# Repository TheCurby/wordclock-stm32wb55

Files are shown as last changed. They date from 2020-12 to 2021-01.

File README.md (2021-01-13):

# Introduction
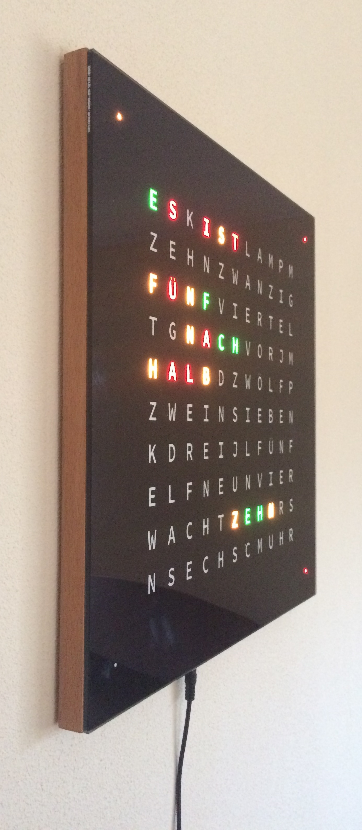
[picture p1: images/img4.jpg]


**ℹ️`This wordclock project contains a simulator. This simulator is using the same sources as the STM32 project. So you can explore this project without building it.`**

**⚠️`This project contains some small smd parts. You should be able to solder VQFN parts.`**

This wordclock is based on a STM32WB55CEU6 microcontroller placed on a custom printed circuit board.
It is designed using the STM32CubeIDE without LL or HAL Driver, just CMSIS.
It is strongly encapsulated in classes and written in C++.
This project only provides a pcb and the firmware/software. An eclosure has to be designed by yourself.
You have to solder the LEDs directly on the pcb and no stripes are needed. You can use SK6812 or WS2812B.
You can use DS18B20 or DS18S20.

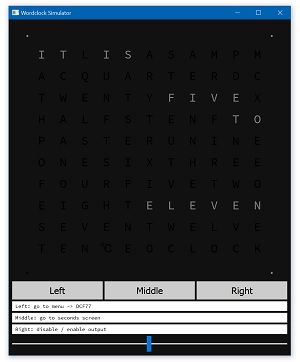
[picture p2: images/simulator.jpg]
On the PCB are three capacitive touch sensors. The microcontroller provides the possibility to use internal touch sensors but I decided to use MTCH105 instead. The sensors are placed directly in copper. As an alternative there is a socket to plug in mechanical switches.

The STM32WB55CEU6 provides the possibility of BLE connectivity on chip. The antenna is implemented on the PCB. There is no app programmed yet and no support implemented in the firmware yet. Feel free to contribute this. 
The wordclock is designed to work without external tools like apps or remote control. The goal is that every functionality can be configured using the cap keys of the clock and an app should only be optional and should not deliver additional possibilities.

Of course you can use any DCF77 module you want. But the PCB and firmware is designed to use the following module: https://de.elv.com/dcf-empfangsmodul-dcf-2-091610

The clock can be powered using a 5V to 18V supply. 

<table border="0" style="border:0px;">
<tr><td>
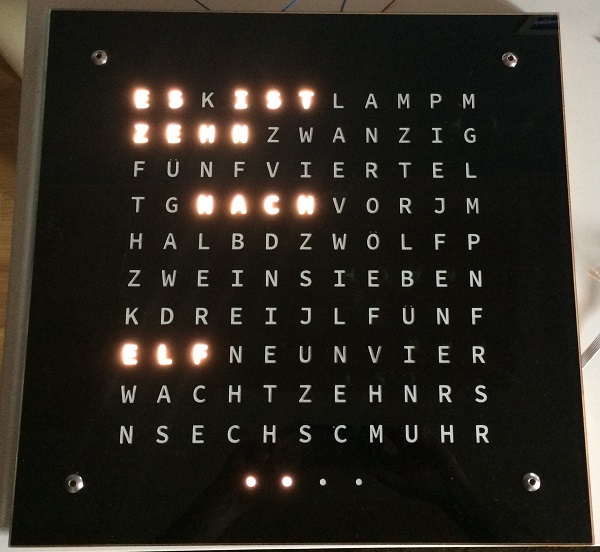
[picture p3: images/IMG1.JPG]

</td><td>
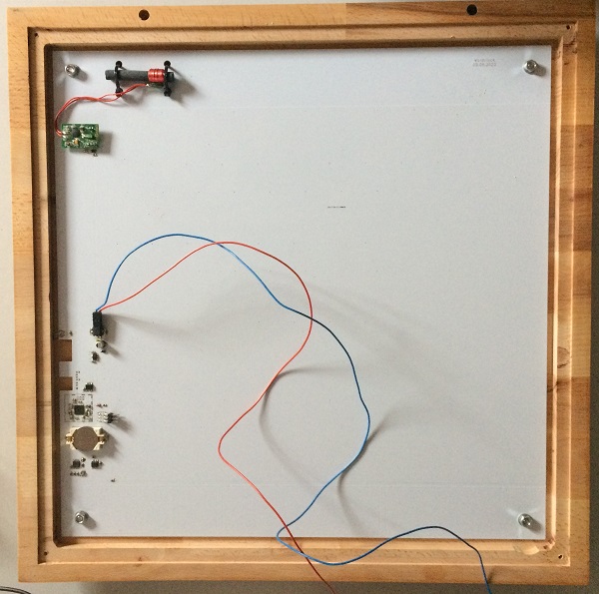
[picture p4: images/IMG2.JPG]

</td></tr></table>

# ✔ Features
* Shows Time, Seconds and temperature (0.2°C steps using the dots to display)
* Enable / Disable the output like an old television with a red dot indicating
* Enable / Disable the DCF77 receiver
* Setting the clock manually
* Setting Color (RGBW)
  * Five different color modes:
    * Normal -> whole screen gets a color mixed by choosen colors
	* Each word gets a different color -> color is randomly mixed by choosen colors 
	* Each letter gets a different color -> color is randomly mixed by choosen colors 
	* Each word gets a different color -> one color from choosen colors 
	* Each letter gets a different color -> one color from choosen colors 
* Setting the LDR configuration for automatic luminosity correction
* Choosing the animation (switching between 5 minute steps)
  * No Animation
  * Random Animation
  * Fading in/out
  * Moving with random direction
  * Plopping randomly in/out
  * Falling down
  * Green Matrix
  * Teletype
* Enable / Disable night mode
* Supported languages: German, Dutch, English, Italian

# ⌛ In progress
* implementing languages (French, Spanish)
* finalize description
* implementing BLE support (firmware, app) and app connectivity
* commentating whole source code

# 🏁 Features planed for next version
None.
  
# ℹ️ Things that won't be implemented 
There are many wordclock projects out there. Many of them have hundreds of functionalities and are overengineered in my opinion. This project is meant to provide only useful features. So the following things **won't** be implemented:
Of course there is no guarantee that I will change my mind.

* Games like tetris etc.
* Updates over Air: Because everyone needs a ST-Link for Development/Deployment, it is very cheap and you can get it almost everywhere so buy it 😉
* Scrolling text and weather report: In my opinion the LED matrix is not suitable for this kind of stuff
* Overlays
* Sounds
* remote control: Because everyone has a smartphone today

# ⚠️ Issues
Firmware:
* Each dots gets different color if they should get the same in Colorful2 oder Word2 mode

# 💻 Simulator
The simulator of this project is using the same sources as the microcontroller project. Any changes in these sources will appear on the next build of the simulator. For this, the directory structure must remain the same.
The three bottons on the bottom correspond to the touch screens on the pcb of the wordclock.
The simulator is giving you some info what you can do with these buttons.

# 💾 Layouts
For every language there is a .svg file in the project. The font used is Source Code Pro Semibold. The .svg files have the right spaces between the letters and dots, but pay attention to the size and position of the frame and hidden elements. The .svg files are meant to use for plotters.

**Attention: Every front has a '°C' on the last line in __one__ letter place! In the tables below it takes __two__ places!**

<table>
	<tr>
		<td>English</td><td>German</td><td>Dutch</td><td>Italian</td><td>Spanish</td>
	</tr>
	<tr>
		<td><pre>IT-IS--AMPM
--QUARTER--
TWENTYFIVE-
HALF-TEN-TO
PAST---NINE
ONESIXTHREE
FOURFIVETWO
EIGHTELEVEN
SEVENTWELVE
TEN℃-OCLOCK</pre></td>
		<td><pre>ES-IST-AMPM
ZEHNZWANZIG
FÜNFVIERTEL
--NACHVOR--
HALB-ZWÖLF-
ZWEI-SIEBEN
-DREI--FÜNF
ELFNEUNVIER
-ACHTZEHN--
-SECHS℃-UHR</pre></td>
		<td><pre>HET-IS-VIJF
TIEN---AMPM
OVER--KWART
VOOR---OVER
HALF---ÉÉN-
TWEE---DRIE
VIERVIJFZES
ZEVEN-NEGEN
ACHTTIENELF
TWAALF℃-UUR</pre></td>
	<td><pre>SONO-LE----
È-LUNA-DUEZ
TREOTTONOVE
DIECIUNDICI
DODICISETTE
QUATTROCSEI
CINQUE-MENO
E-UN-QUARTO
VENTICINQUE
DIECI℃MEZZA
</pre></td>
	<td><pre>TODO</pre></td>
	</tr>
</table>

# 📃 Firmware
TODO: Description following like how to change the mapping of the leds or how to add animations ...

# PCB
The pcb is designed in KiCad. All libraries for symbols and footprints are delivered  with the project and there are no libs used directly from the KiCad installation.
Each LED has a 100nF capacitor but since there is a very big GND and +5V plane I never used or needed them. Nonetheless, it is **recommended** to equip them.

The board size is 370x370mm. The distances of the LEDs are:
* LED -> PCB edge: 50mm
* LED -> LED (x axis): 27mm
* LED -> LED (y axis): 30mm

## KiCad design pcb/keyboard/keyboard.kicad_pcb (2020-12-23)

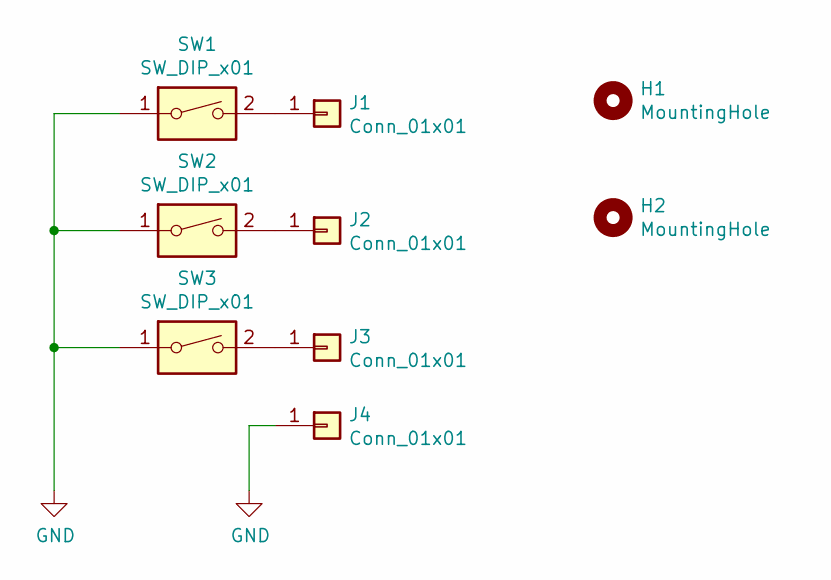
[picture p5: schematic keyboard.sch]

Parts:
H1, H2: MountingHole; MountingHole_5mm
J1, J2, J3, J4: Conn_01x01; pin
SW1, SW2, SW3: SW_DIP_x01; Tl1105_RA

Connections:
GND: J4.1, SW1.1, SW2.1, SW3.1
unnamed: J1.1, SW1.2
unnamed: J2.1, SW2.2
unnamed: J3.1, SW3.2

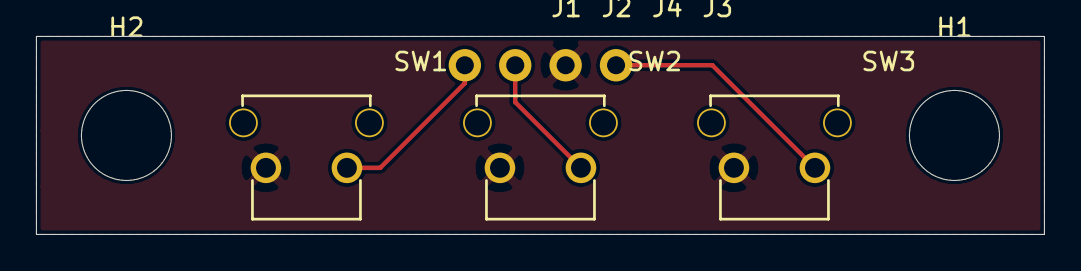
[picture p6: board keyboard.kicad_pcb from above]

Board: 2 copper layers, 56.0 x 11.0 mm, 9 parts (0 on the bottom side), 4 nets.

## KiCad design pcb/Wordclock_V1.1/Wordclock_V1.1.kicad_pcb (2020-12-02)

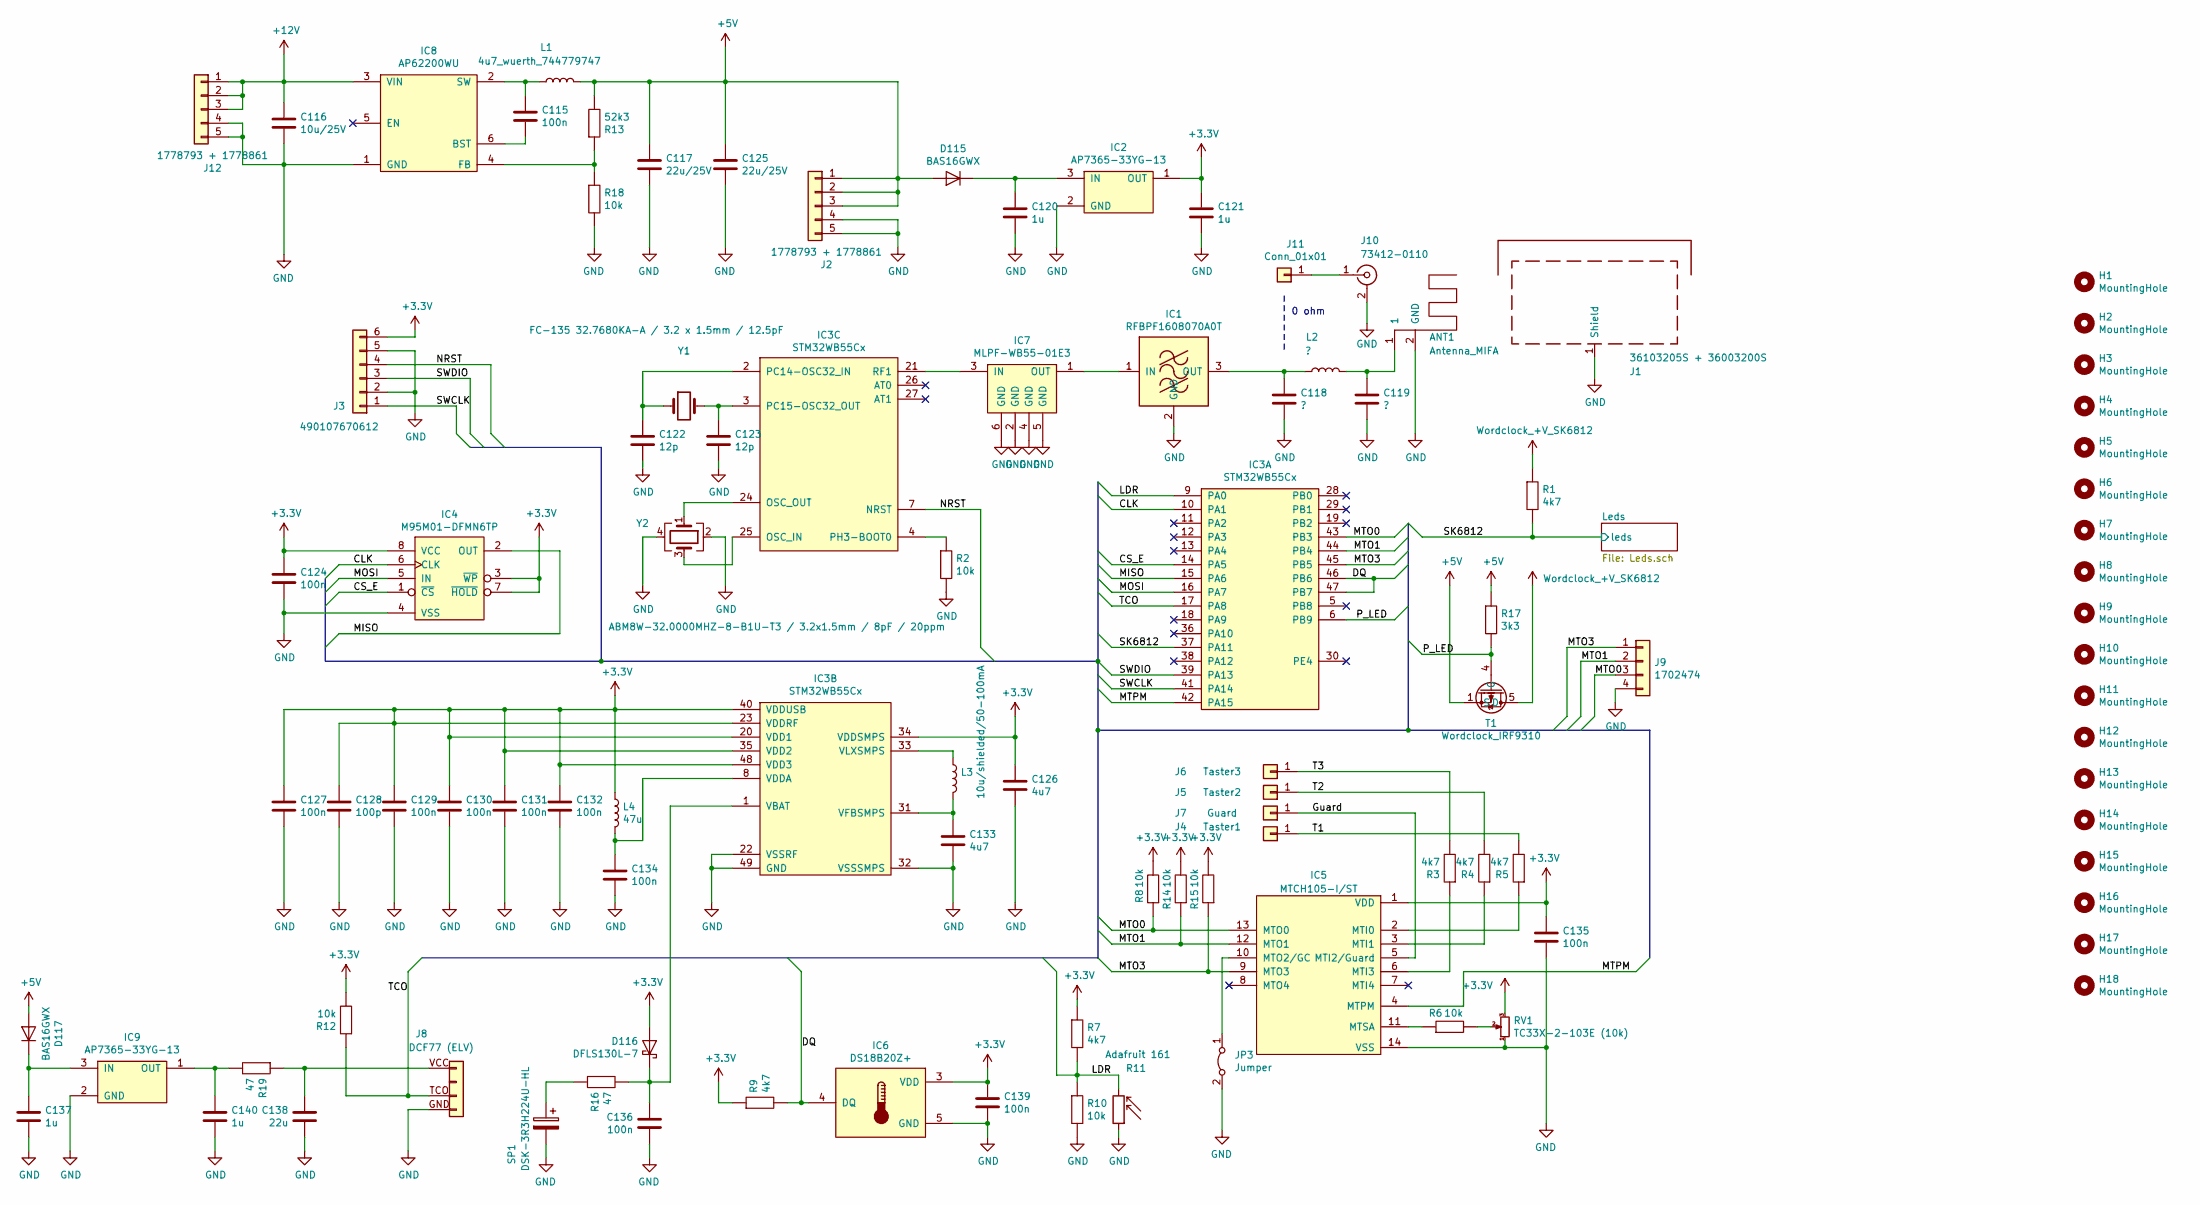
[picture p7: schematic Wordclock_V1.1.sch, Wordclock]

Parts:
ANT1: Antenna_MIFA; invertedf_Kopie
C115, C124, C135, C139: 100n; C_0805_2012Metric
C116: 10u/25V; C_1210_3225Metric
C117, C125: 22u/25V; C_1210_3225Metric
C118, C119: ?; C_0603_1608Metric
C120, C121, C137, C140: 1u; C_0805_2012Metric
C122, C123: 12p; C_0603_1608Metric
C126, C133: 4u7; C_0603_1608Metric
C127, C129, C130, C131, C132, C134, C136: 100n; C_0603_1608Metric
C128: 100p; C_0603_1608Metric
C138: 22u; C_1210_3225Metric
D115, D117: BAS16GWX; D_SOD-123
D116: DFLS130L-7; D_PowerDI-123
H1, H2, H3, H4, H5, H6, H7, H8, H9, H10, H11, H12, H13, H14, H15, H16, H17, H18: MountingHole; MountingHole_5mm
IC1: RFBPF1608070A0T
IC2, IC9: AP7365-33YG-13; SOT-89-3
IC3: STM32WB55Cx; VQFN-48-1EP_7x7mm_P0.5mm_EP5.15x5.15mm_ThermalVias
IC4: M95M01-DFMN6TP; SO-8_3.9x4.9mm_P1.27mm
IC5: MTCH105-I/ST; TSSOP-14_4.4x5mm_P0.65mm
IC6: DS18B20Z+; SO-8_3.9x4.9mm_P1.27mm
IC7: MLPF-WB55-01E3
IC8: AP62200WU; TSOT-26
J1: 36103205S + 36003200S; Wuerth_36103205_20x20mm
J2, J12: 1778793 + 1778861; TerminalBlock_Phoenix_PTSM-0,5-5-HH-2,5-SMD_R32
J3: 490107670612
J4: Taster1; pad
J5: Taster2; pad
J6: Taster3; pad
J7: Guard; pad
J8: DCF77 (ELV); DCF77_ELV
J9: 1702474; TerminalBlock_Phoenix_PTSM-0,5-4-2,5-V-SMD_1x04-1MP_P2.50mm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
J10: 73412-0110; U.FL_Molex_MCRF_73412-0110_Vertical
J11: Conn_01x01; pad_0603
JP3: Jumper; SolderJumper-2_P1.3mm_Open_TrianglePad1.0x1.5mm
L1: 4u7_wuerth_744779747; 744779747
L2: ?; L_0603_1608Metric
L3: 10u/shielded/50-100mA; L_0603_1608Metric
L4: 47u; L_0603_1608Metric
R1, R3, R4, R5, R7, R9: 4k7; R_0805_2012Metric
R2, R6, R8, R10, R12, R14, R15, R18: 10k; R_0805_2012Metric
R11: Adafruit 161; R_LDR_4.9x4.2mm_P2.54mm_Vertical
R13: 52k3; R_0805_2012Metric
R16, R19: 47; R_0805_2012Metric
R17: 3k3; R_0805_2012Metric
RV1: TC33X-2-103E (10k); Potentiometer_Bourns_TC33X_Vertical
SP1: DSK-3R3H224U-HL
T1: Wordclock_IRF9310; SO-8_3.9x4.9mm_P1.27mm
Y1: FC-135 32.7680KA-A / 3.2 x 1.5mm / 12.5pF; Crystal_Epson_FC135
Y2: ABM8W-32.0000MHZ-8-B1U-T3 / 3.2x1.5mm / 8pF / 20p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; Crystal_SMD_Abracon_ABM8G-4Pin_3.2x2.5mm

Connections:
+3V3: C121.1, C124.1, C126.1, C127.1, C128.1, C129.1, C130.1, C131.1, C132.1, C135.1, C139.1, D116.2 (A), IC2.1 (OUT), IC3.20 (VDD1), IC3.23 (VDDRF), IC3.34 (VDDSMPS), IC3.35 (VDD2), IC3.40 (VDDUSB), IC3.48 (VDD3), IC4.3 (~WP), IC4.7 (~HOLD), IC4.8 (VCC), IC5.1 (VDD), IC6.3 (VDD), J3.6, L4.1, R7.1, R8.2, R9.1, R12.2, R14.2, R15.2, RV1.3
+5V: C117.1, C125.1, D115.2 (A), D117.2 (A), J2.1, J2.2, J2.3, L1.2, R13.2, R17.1, T1.1 (S), T1.2 (S), T1.3 (S)
+12V: C116.1, IC8.3 (VIN), J12.1, J12.2, J12.3
+SK6812: R1.1, T1.5 (D), T1.6 (D), T1.7 (D), T1.8 (D); also elsewhere on the board
/CLK: IC3.10 (PA1), IC4.6 (CLK)
/CS_E: IC3.14 (PA5), IC4.1 (~CS)
/DQ: IC3.46 (PB6), IC3.47 (PB7), IC6.4 (DQ), R9.2
/Guard: IC5.5 (MTI2/Guard), J7.1
/LDR: IC3.9 (PA0), R7.2, R10.1, R11.2
/MISO: IC3.15 (PA6), IC4.2 (OUT)
/MOSI: IC3.16 (PA7), IC4.5 (IN)
/MTO0: IC3.43 (PB3), IC5.13 (MTO0), J9.3, R8.1
/MTO1: IC3.44 (PB4), IC5.12 (MTO1), J9.2, R14.1
/MTO3: IC3.45 (PB5), IC5.9 (MTO3), J9.1, R15.1
/MTPM: IC3.42 (PA15), IC5.4 (MTPM)
/NRST: IC3.7 (NRST), J3.4
/P_LED: IC3.6 (PB9), R17.2, T1.4 (G)
/SK6812: IC3.37 (PA11), R1.2; also elsewhere on the board
/SWCLK: IC3.41 (PA14), J3.1
/SWDIO: IC3.39 (PA13), J3.3
/T1: J4.1, R5.2
/T2: J5.1, R4.2
/T3: J6.1, R3.2
/TCO: IC3.17 (PA8), J8.TCO, R12.1
GND: ANT1.2 (GND), C116.2, C117.2, C118.2, C119.2, C120.2, C121.2, C122.2, C123.2, C124.2, C125.2, C126.2, C127.2, C128.2, C129.2, C130.2, C131.2, C132.2, C133.2, C134.2, C135.2, C136.2, C137.2, C138.2, C139.2, C140.2, IC1.2 (GND), IC1.4 (GND), IC2.2 (GND), IC3.22 (VSSRF), IC3.32 (VSSSMPS), IC3.49 (GND), IC4.4 (VSS), IC5.14 (VSS), IC6.5 (GND), IC7.2 (GND), IC7.4 (GND), IC7.5 (GND), IC7.6 (GND), IC8.1 (GND), IC9.2 (GND), J1.1, J2.4, J2.5, J3.2, J3.5, J8.GND, J9.4, J10.2 (Ext), J12.4, J12.5, JP3.2 (B), R2.2, R10.2, R11.1, R18.2, RV1.1, SP1.2, Y2.2, Y2.4; also elsewhere on the board
unnamed: ANT1.1, C119.1, L2.2
unnamed: C115.1, IC8.2 (SW), L1.1
unnamed: C115.2, IC8.6 (BST)
unnamed: C118.1, IC1.3 (OUT), L2.1
unnamed: C120.1, D115.1 (K), IC2.3 (IN)
unnamed: C122.1, IC3.2 (PC14-OSC32_IN), Y1.1
unnamed: C123.1, IC3.3 (PC15-OSC32_OUT), Y1.2
unnamed: C133.1, IC3.31 (VFBSMPS), L3.2
unnamed: C134.1, IC3.8 (VDDA), L4.2
unnamed: C136.1, D116.1 (K), IC3.1 (VBAT), R16.2
unnamed: C137.1, D117.1 (K), IC9.3 (IN)
unnamed: C138.1, J8.VCC, R19.1
unnamed: C140.1, IC9.1 (OUT), R19.2
unnamed: IC1.1 (IN), IC7.1 (OUT)
unnamed: IC3.4 (PH3-BOOT0), R2.1
unnamed: IC3.21 (RF1), IC7.3 (IN)
unnamed: IC3.24 (OSC_OUT), Y2.1
unnamed: IC3.25 (OSC_IN), Y2.3
unnamed: IC3.33 (VLXSMPS), L3.1
unnamed: IC5.2 (MTI0), R5.1
unnamed: IC5.3 (MTI1), R4.1
unnamed: IC5.6 (MTI3), R3.1
unnamed: IC5.10 (MTO2/GC), JP3.1 (A)
unnamed: IC5.11 (MTSA), R6.1
unnamed: IC8.4 (FB), R13.1, R18.1
unnamed: J10.1 (In), J11.1
unnamed: R6.2, RV1.2
unnamed: R16.1, SP1.1

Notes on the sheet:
0 ohm

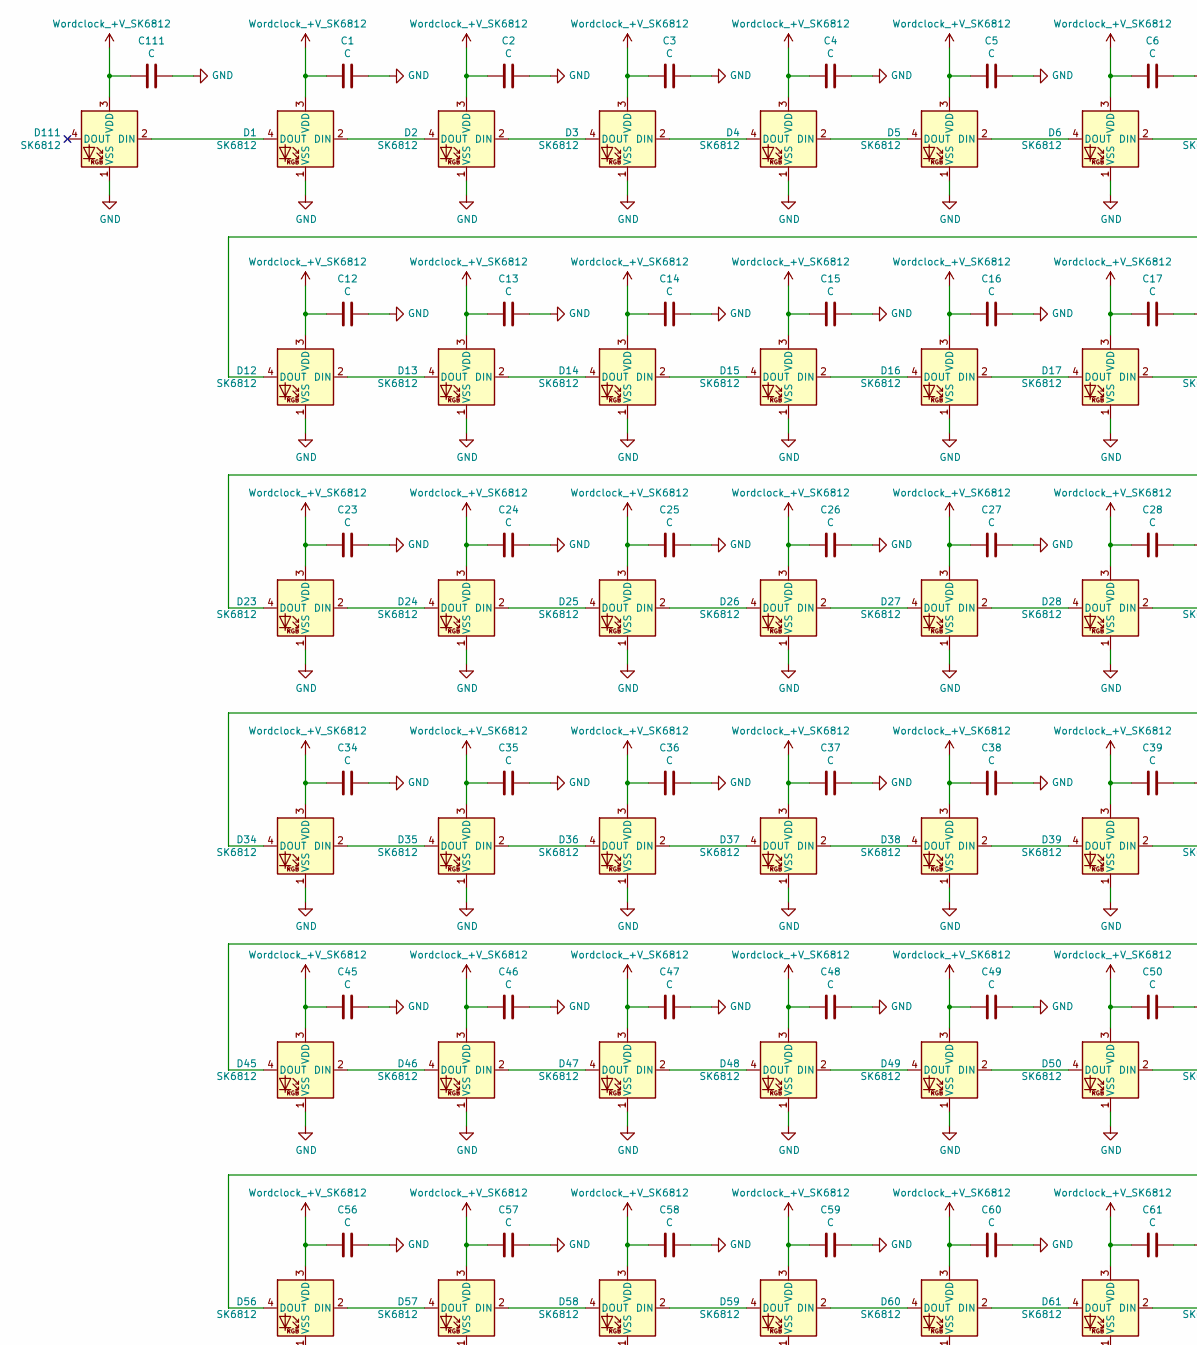
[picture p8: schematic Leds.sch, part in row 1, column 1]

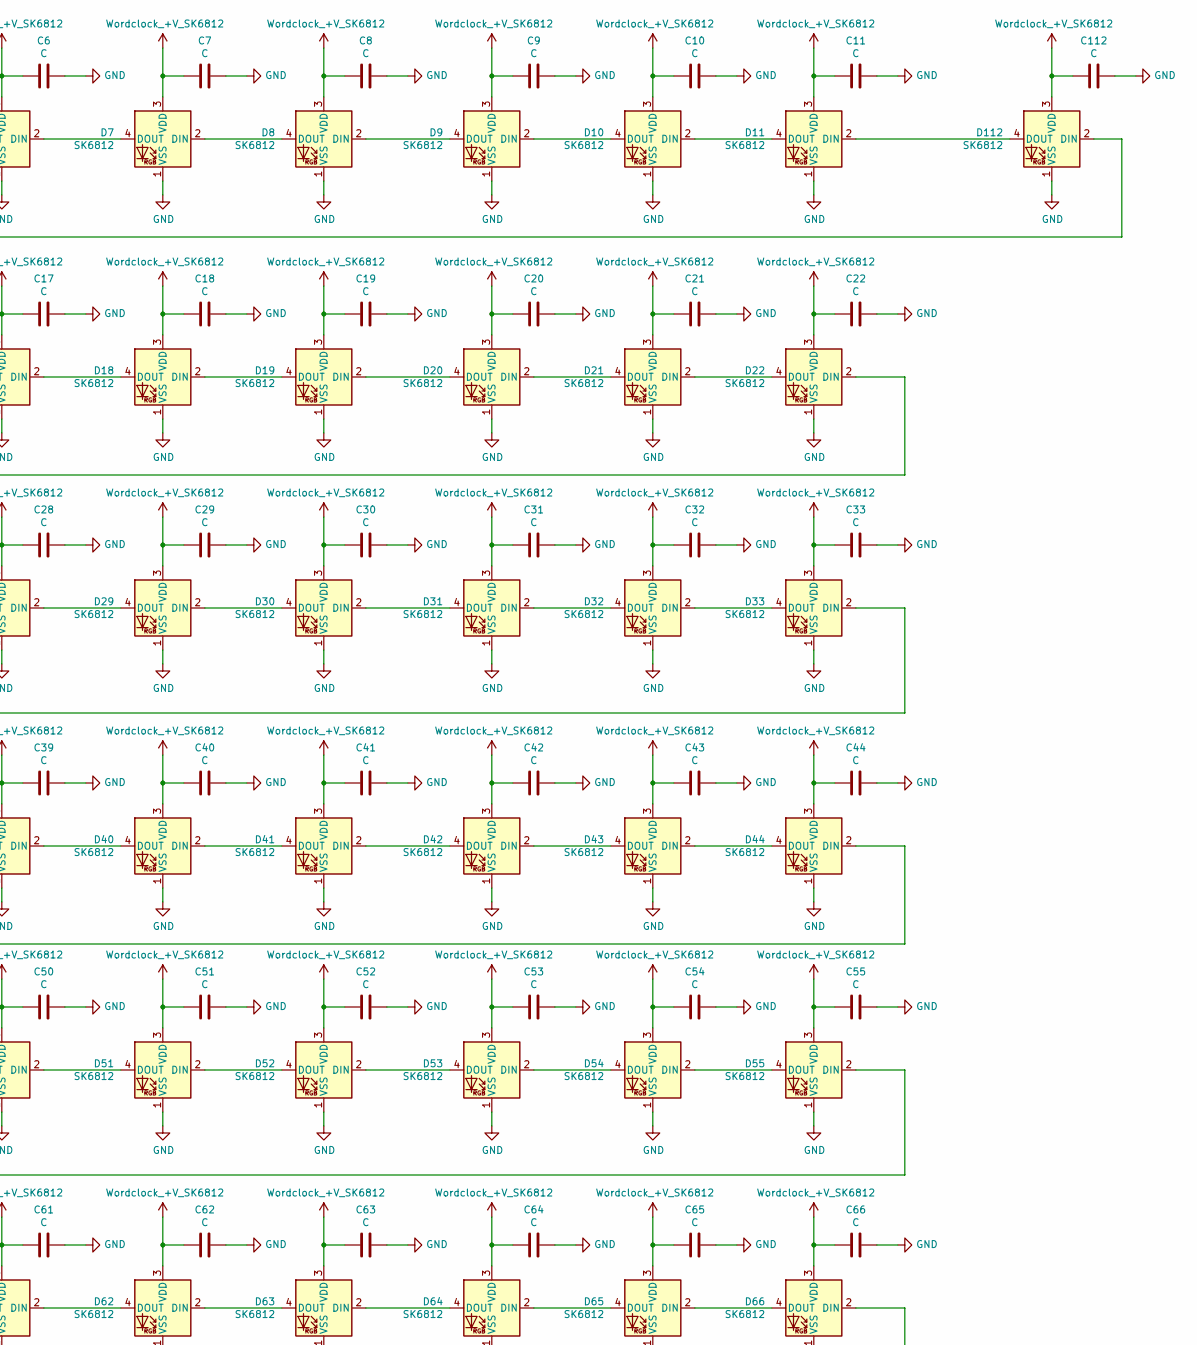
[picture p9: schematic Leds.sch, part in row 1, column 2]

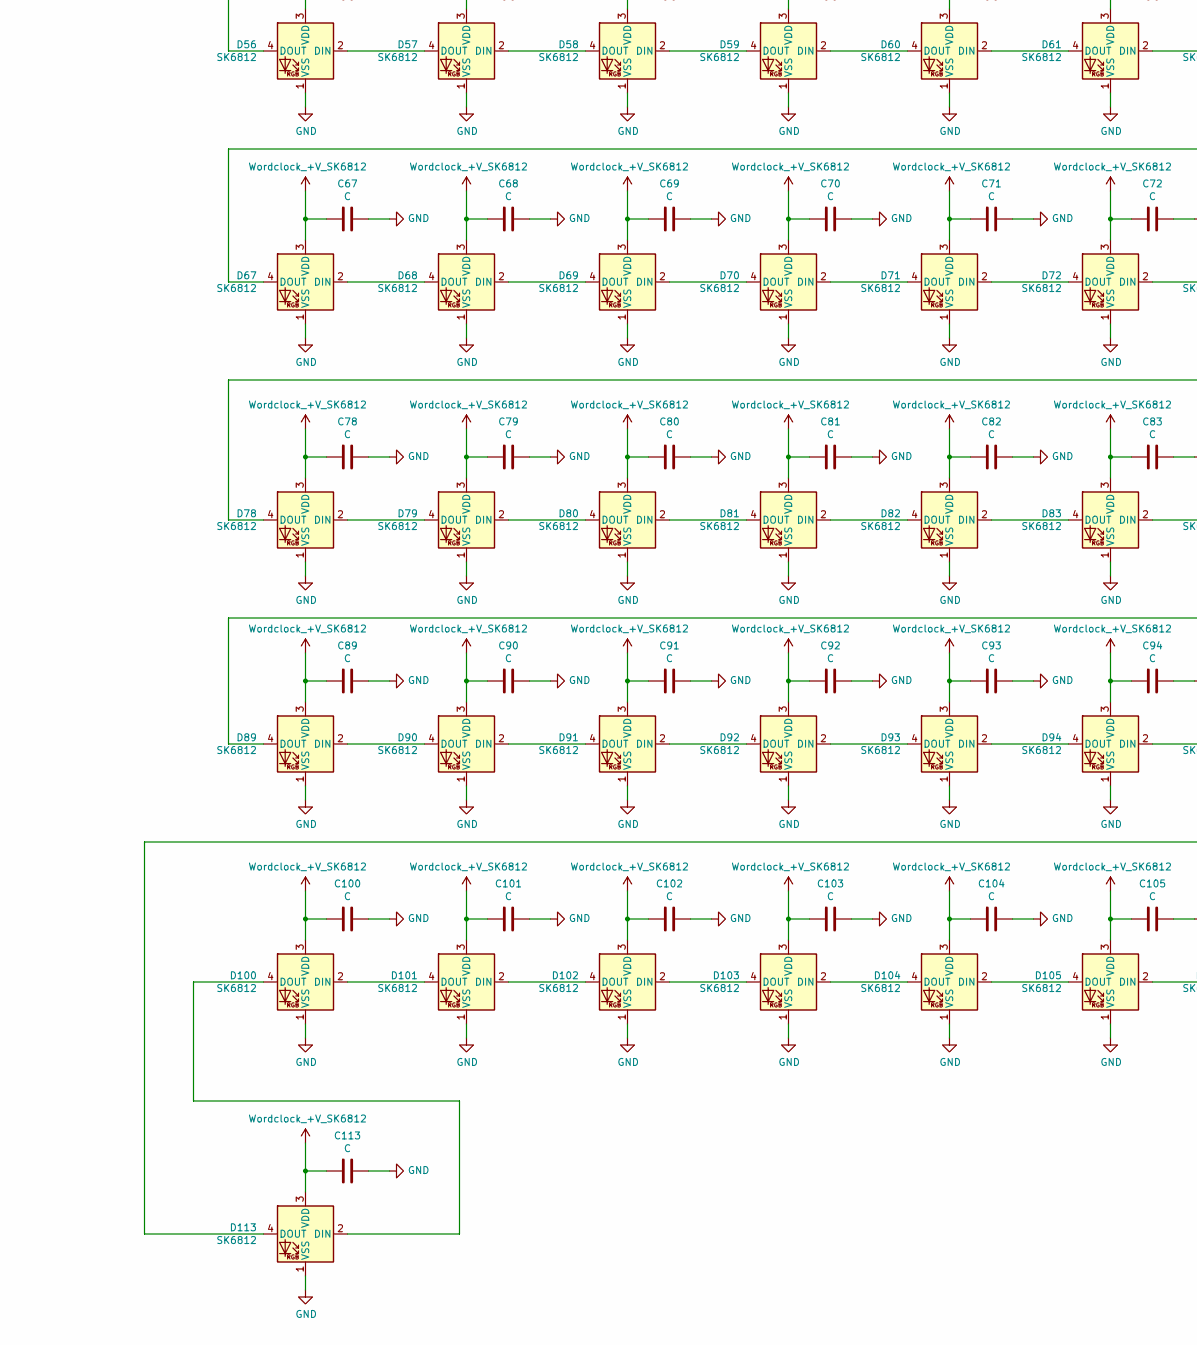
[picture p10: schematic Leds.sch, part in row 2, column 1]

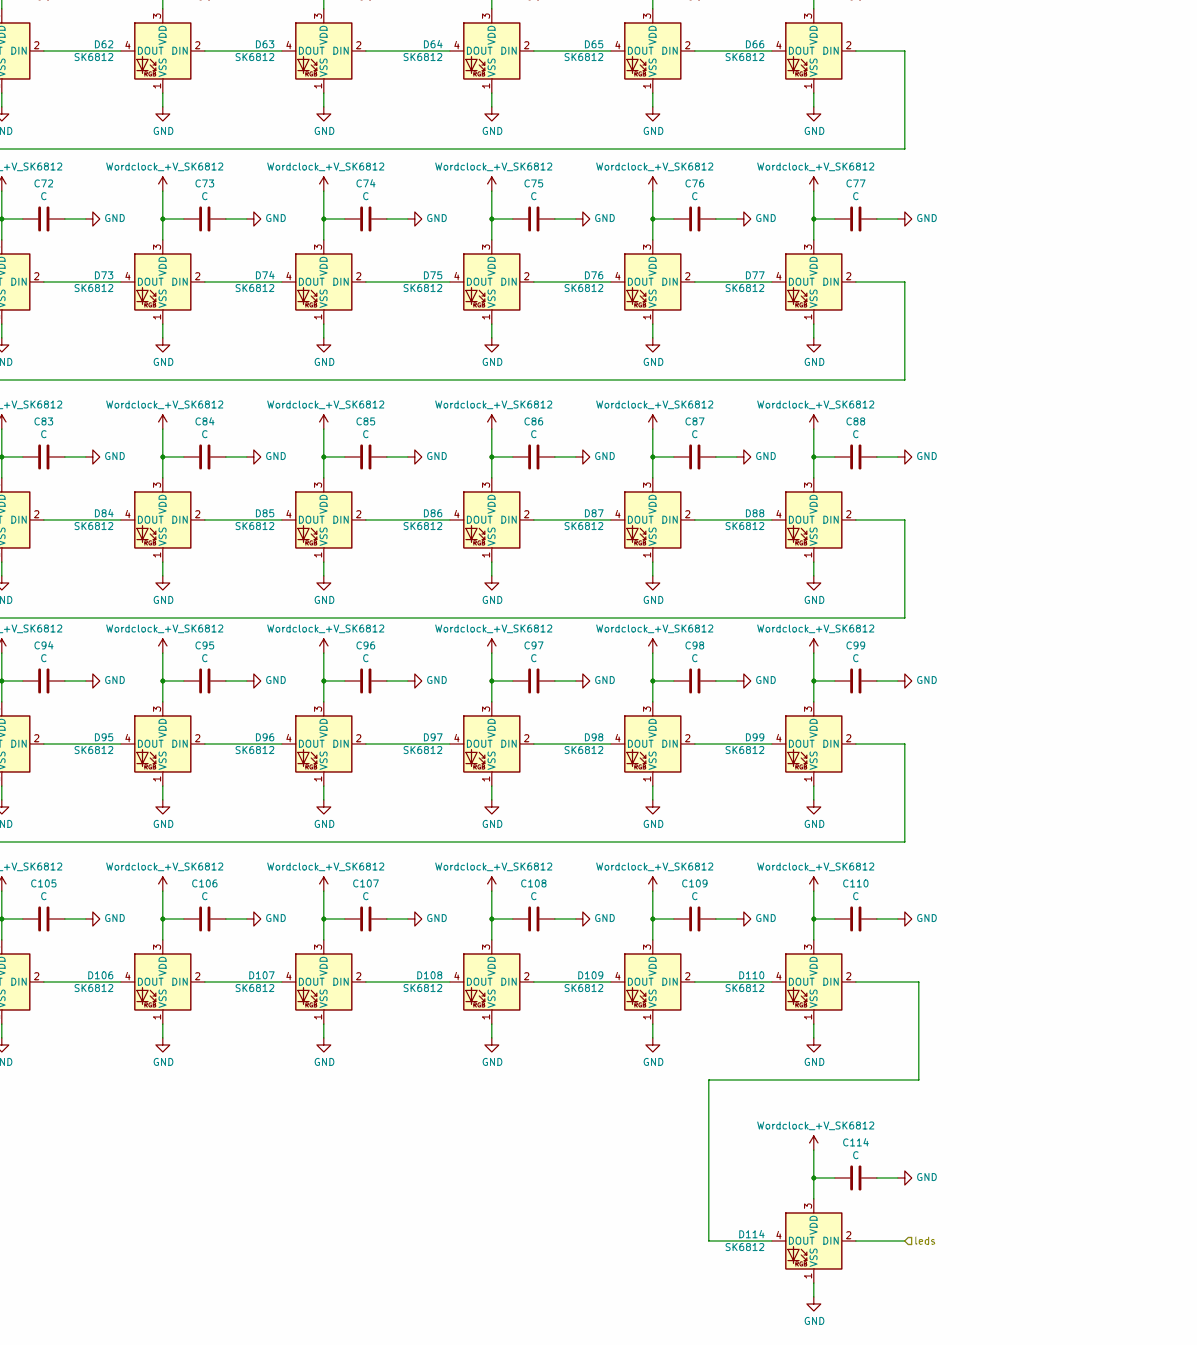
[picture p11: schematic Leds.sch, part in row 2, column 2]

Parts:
C1, C2, C3, C4, C5, C6, C7, C8, C9, C10, C11, C12, C13, C14, C15, C16, C17, C18, C19, C20, C21, C22, C23, C24, C25, C26, C27, C28, C29, C30, C31, C32, C33, C34, C35, C36, C37, C38, C39, C40, C41, C42, C43, C44, C45, C46, C47, C48, C49, C50, C51, C52, C53, C54, C55, C56, C57, C58, C59, C60, C61, C62, C63, C64, C65, C66, C67, C68, C69, C70, C71, C72, C73, C74, C75, C76, C77, C78, C79, C80, C81, C82, C83, C84, C85, C86, C87, C88, C89, C90, C91, C92, C93, C94, C95, C96, C97, C98, C99, C100, C101, C102, C103, C104, C105, C106, C107, C108, C109, C110, C111, C112, C113, C114: C; C_0805_2012Metric
D1, D2, D3, D4, D5, D6, D7, D8, D9, D10, D11, D12, D13, D14, D15, D16, D17, D18, D19, D20, D21, D22, D23, D24, D25, D26, D27, D28, D29, D30, D31, D32, D33, D34, D35, D36, D37, D38, D39, D40, D41, D42, D43, D44, D45, D46, D47, D48, D49, D50, D51, D52, D53, D54, D55, D56, D57, D58, D59, D60, D61, D62, D63, D64, D65, D66, D67, D68, D69, D70, D71, D72, D73, D74, D75, D76, D77, D78, D79, D80, D81, D82, D83, D84, D85, D86, D87, D88, D89, D90, D91, D92, D93, D94, D95, D96, D97, D98, D99, D100, D101, D102, D103, D104, D105, D106, D107, D108, D109, D110, D111, D112, D113, D114: SK6812; LED_SK6812_PLCC4_5.0x5.0mm_P3.2mm

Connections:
+SK6812: C1.2, C2.2, C3.2, C4.2, C5.2, C6.2, C7.2, C8.2, C9.2, C10.2, C11.2, C12.2, C13.2, C14.2, C15.2, C16.2, C17.2, C18.2, C19.2, C20.2, C21.2, C22.2, C23.2, C24.2, C25.2, C26.2, C27.2, C28.2, C29.2, C30.2, C31.2, C32.2, C33.2, C34.2, C35.2, C36.2, C37.2, C38.2, C39.2, C40.2, C41.2, C42.2, C43.2, C44.2, C45.2, C46.2, C47.2, C48.2, C49.2, C50.2, C51.2, C52.2, C53.2, C54.2, C55.2, C56.2, C57.2, C58.2, C59.2, C60.2, C61.2, C62.2, C63.2, C64.2, C65.2, C66.2, C67.2, C68.2, C69.2, C70.2, C71.2, C72.2, C73.2, C74.2, C75.2, C76.2, C77.2, C78.2, C79.2, C80.2, C81.2, C82.2, C83.2, C84.2, C85.2, C86.2, C87.2, C88.2, C89.2, C90.2, C91.2, C92.2, C93.2, C94.2, C95.2, C96.2, C97.2, C98.2, C99.2, C100.2, C101.2, C102.2, C103.2, C104.2, C105.2, C106.2, C107.2, C108.2, C109.2, C110.2, C111.2, C112.2, C113.2, C114.2, D1.3 (VDD), D2.3 (VDD), D3.3 (VDD), D4.3 (VDD), D5.3 (VDD), D6.3 (VDD), D7.3 (VDD), D8.3 (VDD), D9.3 (VDD), D10.3 (VDD), D11.3 (VDD), D12.3 (VDD), D13.3 (VDD), D14.3 (VDD), D15.3 (VDD), D16.3 (VDD), D17.3 (VDD), D18.3 (VDD), D19.3 (VDD), D20.3 (VDD), D21.3 (VDD), D22.3 (VDD), D23.3 (VDD), D24.3 (VDD), D25.3 (VDD), D26.3 (VDD), D27.3 (VDD), D28.3 (VDD), D29.3 (VDD), D30.3 (VDD), D31.3 (VDD), D32.3 (VDD), D33.3 (VDD), D34.3 (VDD), D35.3 (VDD), D36.3 (VDD), D37.3 (VDD), D38.3 (VDD), D39.3 (VDD), D40.3 (VDD), D41.3 (VDD), D42.3 (VDD), D43.3 (VDD), D44.3 (VDD), D45.3 (VDD), D46.3 (VDD), D47.3 (VDD), D48.3 (VDD), D49.3 (VDD), D50.3 (VDD), D51.3 (VDD), D52.3 (VDD), D53.3 (VDD), D54.3 (VDD), D55.3 (VDD), D56.3 (VDD), D57.3 (VDD), D58.3 (VDD), D59.3 (VDD), D60.3 (VDD), D61.3 (VDD), D62.3 (VDD), D63.3 (VDD), D64.3 (VDD), D65.3 (VDD), D66.3 (VDD), D67.3 (VDD), D68.3 (VDD), D69.3 (VDD), D70.3 (VDD), D71.3 (VDD), D72.3 (VDD), D73.3 (VDD), D74.3 (VDD), D75.3 (VDD), D76.3 (VDD), D77.3 (VDD), D78.3 (VDD), D79.3 (VDD), D80.3 (VDD), D81.3 (VDD), D82.3 (VDD), D83.3 (VDD), D84.3 (VDD), D85.3 (VDD), D86.3 (VDD), D87.3 (VDD), D88.3 (VDD), D89.3 (VDD), D90.3 (VDD), D91.3 (VDD), D92.3 (VDD), D93.3 (VDD), D94.3 (VDD), D95.3 (VDD), D96.3 (VDD), D97.3 (VDD), D98.3 (VDD), D99.3 (VDD), D100.3 (VDD), D101.3 (VDD), D102.3 (VDD), D103.3 (VDD), D104.3 (VDD), D105.3 (VDD), D106.3 (VDD), D107.3 (VDD), D108.3 (VDD), D109.3 (VDD), D110.3 (VDD), D111.3 (VDD), D112.3 (VDD), D113.3 (VDD), D114.3 (VDD); also elsewhere on the board
/SK6812: D114.2 (DIN); also elsewhere on the board
GND: C1.1, C2.1, C3.1, C4.1, C5.1, C6.1, C7.1, C8.1, C9.1, C10.1, C11.1, C12.1, C13.1, C14.1, C15.1, C16.1, C17.1, C18.1, C19.1, C20.1, C21.1, C22.1, C23.1, C24.1, C25.1, C26.1, C27.1, C28.1, C29.1, C30.1, C31.1, C32.1, C33.1, C34.1, C35.1, C36.1, C37.1, C38.1, C39.1, C40.1, C41.1, C42.1, C43.1, C44.1, C45.1, C46.1, C47.1, C48.1, C49.1, C50.1, C51.1, C52.1, C53.1, C54.1, C55.1, C56.1, C57.1, C58.1, C59.1, C60.1, C61.1, C62.1, C63.1, C64.1, C65.1, C66.1, C67.1, C68.1, C69.1, C70.1, C71.1, C72.1, C73.1, C74.1, C75.1, C76.1, C77.1, C78.1, C79.1, C80.1, C81.1, C82.1, C83.1, C84.1, C85.1, C86.1, C87.1, C88.1, C89.1, C90.1, C91.1, C92.1, C93.1, C94.1, C95.1, C96.1, C97.1, C98.1, C99.1, C100.1, C101.1, C102.1, C103.1, C104.1, C105.1, C106.1, C107.1, C108.1, C109.1, C110.1, C111.1, C112.1, C113.1, C114.1, D1.1 (VSS), D2.1 (VSS), D3.1 (VSS), D4.1 (VSS), D5.1 (VSS), D6.1 (VSS), D7.1 (VSS), D8.1 (VSS), D9.1 (VSS), D10.1 (VSS), D11.1 (VSS), D12.1 (VSS), D13.1 (VSS), D14.1 (VSS), D15.1 (VSS), D16.1 (VSS), D17.1 (VSS), D18.1 (VSS), D19.1 (VSS), D20.1 (VSS), D21.1 (VSS), D22.1 (VSS), D23.1 (VSS), D24.1 (VSS), D25.1 (VSS), D26.1 (VSS), D27.1 (VSS), D28.1 (VSS), D29.1 (VSS), D30.1 (VSS), D31.1 (VSS), D32.1 (VSS), D33.1 (VSS), D34.1 (VSS), D35.1 (VSS), D36.1 (VSS), D37.1 (VSS), D38.1 (VSS), D39.1 (VSS), D40.1 (VSS), D41.1 (VSS), D42.1 (VSS), D43.1 (VSS), D44.1 (VSS), D45.1 (VSS), D46.1 (VSS), D47.1 (VSS), D48.1 (VSS), D49.1 (VSS), D50.1 (VSS), D51.1 (VSS), D52.1 (VSS), D53.1 (VSS), D54.1 (VSS), D55.1 (VSS), D56.1 (VSS), D57.1 (VSS), D58.1 (VSS), D59.1 (VSS), D60.1 (VSS), D61.1 (VSS), D62.1 (VSS), D63.1 (VSS), D64.1 (VSS), D65.1 (VSS), D66.1 (VSS), D67.1 (VSS), D68.1 (VSS), D69.1 (VSS), D70.1 (VSS), D71.1 (VSS), D72.1 (VSS), D73.1 (VSS), D74.1 (VSS), D75.1 (VSS), D76.1 (VSS), D77.1 (VSS), D78.1 (VSS), D79.1 (VSS), D80.1 (VSS), D81.1 (VSS), D82.1 (VSS), D83.1 (VSS), D84.1 (VSS), D85.1 (VSS), D86.1 (VSS), D87.1 (VSS), D88.1 (VSS), D89.1 (VSS), D90.1 (VSS), D91.1 (VSS), D92.1 (VSS), D93.1 (VSS), D94.1 (VSS), D95.1 (VSS), D96.1 (VSS), D97.1 (VSS), D98.1 (VSS), D99.1 (VSS), D100.1 (VSS), D101.1 (VSS), D102.1 (VSS), D103.1 (VSS), D104.1 (VSS), D105.1 (VSS), D106.1 (VSS), D107.1 (VSS), D108.1 (VSS), D109.1 (VSS), D110.1 (VSS), D111.1 (VSS), D112.1 (VSS), D113.1 (VSS), D114.1 (VSS); also elsewhere on the board
unnamed: D1.2 (DIN), D2.4 (DOUT)
unnamed: D1.4 (DOUT), D111.2 (DIN)
unnamed: D2.2 (DIN), D3.4 (DOUT)
unnamed: D3.2 (DIN), D4.4 (DOUT)
unnamed: D4.2 (DIN), D5.4 (DOUT)
unnamed: D5.2 (DIN), D6.4 (DOUT)
unnamed: D6.2 (DIN), D7.4 (DOUT)
unnamed: D7.2 (DIN), D8.4 (DOUT)
unnamed: D8.2 (DIN), D9.4 (DOUT)
unnamed: D10.2 (DIN), D11.4 (DOUT)
unnamed: D9.2 (DIN), D10.4 (DOUT)
unnamed: D11.2 (DIN), D112.4 (DOUT)
unnamed: D12.2 (DIN), D13.4 (DOUT)
unnamed: D13.2 (DIN), D14.4 (DOUT)
unnamed: D14.2 (DIN), D15.4 (DOUT)
unnamed: D15.2 (DIN), D16.4 (DOUT)
unnamed: D16.2 (DIN), D17.4 (DOUT)
unnamed: D17.2 (DIN), D18.4 (DOUT)
unnamed: D18.2 (DIN), D19.4 (DOUT)
unnamed: D19.2 (DIN), D20.4 (DOUT)
unnamed: D20.2 (DIN), D21.4 (DOUT)
unnamed: D21.2 (DIN), D22.4 (DOUT)
unnamed: D22.2 (DIN), D23.4 (DOUT)
unnamed: D23.2 (DIN), D24.4 (DOUT)
unnamed: D24.2 (DIN), D25.4 (DOUT)
unnamed: D25.2 (DIN), D26.4 (DOUT)
unnamed: D26.2 (DIN), D27.4 (DOUT)
unnamed: D27.2 (DIN), D28.4 (DOUT)
unnamed: D28.2 (DIN), D29.4 (DOUT)
unnamed: D29.2 (DIN), D30.4 (DOUT)
unnamed: D30.2 (DIN), D31.4 (DOUT)
unnamed: D31.2 (DIN), D32.4 (DOUT)
unnamed: D32.2 (DIN), D33.4 (DOUT)
unnamed: D33.2 (DIN), D34.4 (DOUT)
unnamed: D34.2 (DIN), D35.4 (DOUT)
unnamed: D35.2 (DIN), D36.4 (DOUT)
unnamed: D36.2 (DIN), D37.4 (DOUT)
unnamed: D37.2 (DIN), D38.4 (DOUT)
unnamed: D38.2 (DIN), D39.4 (DOUT)
unnamed: D39.2 (DIN), D40.4 (DOUT)
unnamed: D40.2 (DIN), D41.4 (DOUT)
unnamed: D41.2 (DIN), D42.4 (DOUT)
unnamed: D42.2 (DIN), D43.4 (DOUT)
unnamed: D43.2 (DIN), D44.4 (DOUT)
unnamed: D44.2 (DIN), D45.4 (DOUT)
unnamed: D45.2 (DIN), D46.4 (DOUT)
unnamed: D46.2 (DIN), D47.4 (DOUT)
unnamed: D47.2 (DIN), D48.4 (DOUT)
unnamed: D48.2 (DIN), D49.4 (DOUT)
unnamed: D49.2 (DIN), D50.4 (DOUT)
unnamed: D50.2 (DIN), D51.4 (DOUT)
unnamed: D51.2 (DIN), D52.4 (DOUT)
unnamed: D52.2 (DIN), D53.4 (DOUT)
unnamed: D53.2 (DIN), D54.4 (DOUT)
unnamed: D54.2 (DIN), D55.4 (DOUT)
unnamed: D55.2 (DIN), D56.4 (DOUT)
unnamed: D56.2 (DIN), D57.4 (DOUT)
unnamed: D57.2 (DIN), D58.4 (DOUT)
unnamed: D58.2 (DIN), D59.4 (DOUT)
unnamed: D59.2 (DIN), D60.4 (DOUT)
unnamed: D60.2 (DIN), D61.4 (DOUT)
unnamed: D61.2 (DIN), D62.4 (DOUT)
unnamed: D62.2 (DIN), D63.4 (DOUT)
unnamed: D63.2 (DIN), D64.4 (DOUT)
unnamed: D64.2 (DIN), D65.4 (DOUT)
unnamed: D65.2 (DIN), D66.4 (DOUT)
unnamed: D66.2 (DIN), D67.4 (DOUT)
unnamed: D67.2 (DIN), D68.4 (DOUT)
unnamed: D68.2 (DIN), D69.4 (DOUT)
unnamed: D69.2 (DIN), D70.4 (DOUT)
unnamed: D70.2 (DIN), D71.4 (DOUT)
unnamed: D71.2 (DIN), D72.4 (DOUT)
unnamed: D72.2 (DIN), D73.4 (DOUT)
unnamed: D73.2 (DIN), D74.4 (DOUT)
unnamed: D74.2 (DIN), D75.4 (DOUT)
unnamed: D75.2 (DIN), D76.4 (DOUT)
unnamed: D76.2 (DIN), D77.4 (DOUT)
unnamed: D77.2 (DIN), D78.4 (DOUT)
unnamed: D78.2 (DIN), D79.4 (DOUT)
unnamed: D79.2 (DIN), D80.4 (DOUT)
unnamed: D80.2 (DIN), D81.4 (DOUT)
unnamed: D81.2 (DIN), D82.4 (DOUT)
unnamed: D82.2 (DIN), D83.4 (DOUT)
unnamed: D83.2 (DIN), D84.4 (DOUT)
unnamed: D84.2 (DIN), D85.4 (DOUT)
unnamed: D85.2 (DIN), D86.4 (DOUT)
unnamed: D86.2 (DIN), D87.4 (DOUT)
unnamed: D87.2 (DIN), D88.4 (DOUT)
unnamed: D88.2 (DIN), D89.4 (DOUT)
unnamed: D89.2 (DIN), D90.4 (DOUT)
unnamed: D90.2 (DIN), D91.4 (DOUT)
unnamed: D91.2 (DIN), D92.4 (DOUT)
unnamed: D92.2 (DIN), D93.4 (DOUT)
unnamed: D93.2 (DIN), D94.4 (DOUT)
unnamed: D94.2 (DIN), D95.4 (DOUT)
unnamed: D95.2 (DIN), D96.4 (DOUT)
unnamed: D96.2 (DIN), D97.4 (DOUT)
unnamed: D97.2 (DIN), D98.4 (DOUT)
unnamed: D98.2 (DIN), D99.4 (DOUT)
unnamed: D100.2 (DIN), D101.4 (DOUT)
unnamed: D100.4 (DOUT), D113.2 (DIN)
unnamed: D101.2 (DIN), D102.4 (DOUT)
unnamed: D102.2 (DIN), D103.4 (DOUT)
unnamed: D103.2 (DIN), D104.4 (DOUT)
unnamed: D104.2 (DIN), D105.4 (DOUT)
unnamed: D105.2 (DIN), D106.4 (DOUT)
unnamed: D106.2 (DIN), D107.4 (DOUT)
unnamed: D107.2 (DIN), D108.4 (DOUT)
unnamed: D108.2 (DIN), D109.4 (DOUT)
unnamed: D109.2 (DIN), D110.4 (DOUT)
unnamed: D110.2 (DIN), D114.4 (DOUT)
unnamed: D12.4 (DOUT), D112.2 (DIN)
unnamed: D99.2 (DIN), D113.4 (DOUT)

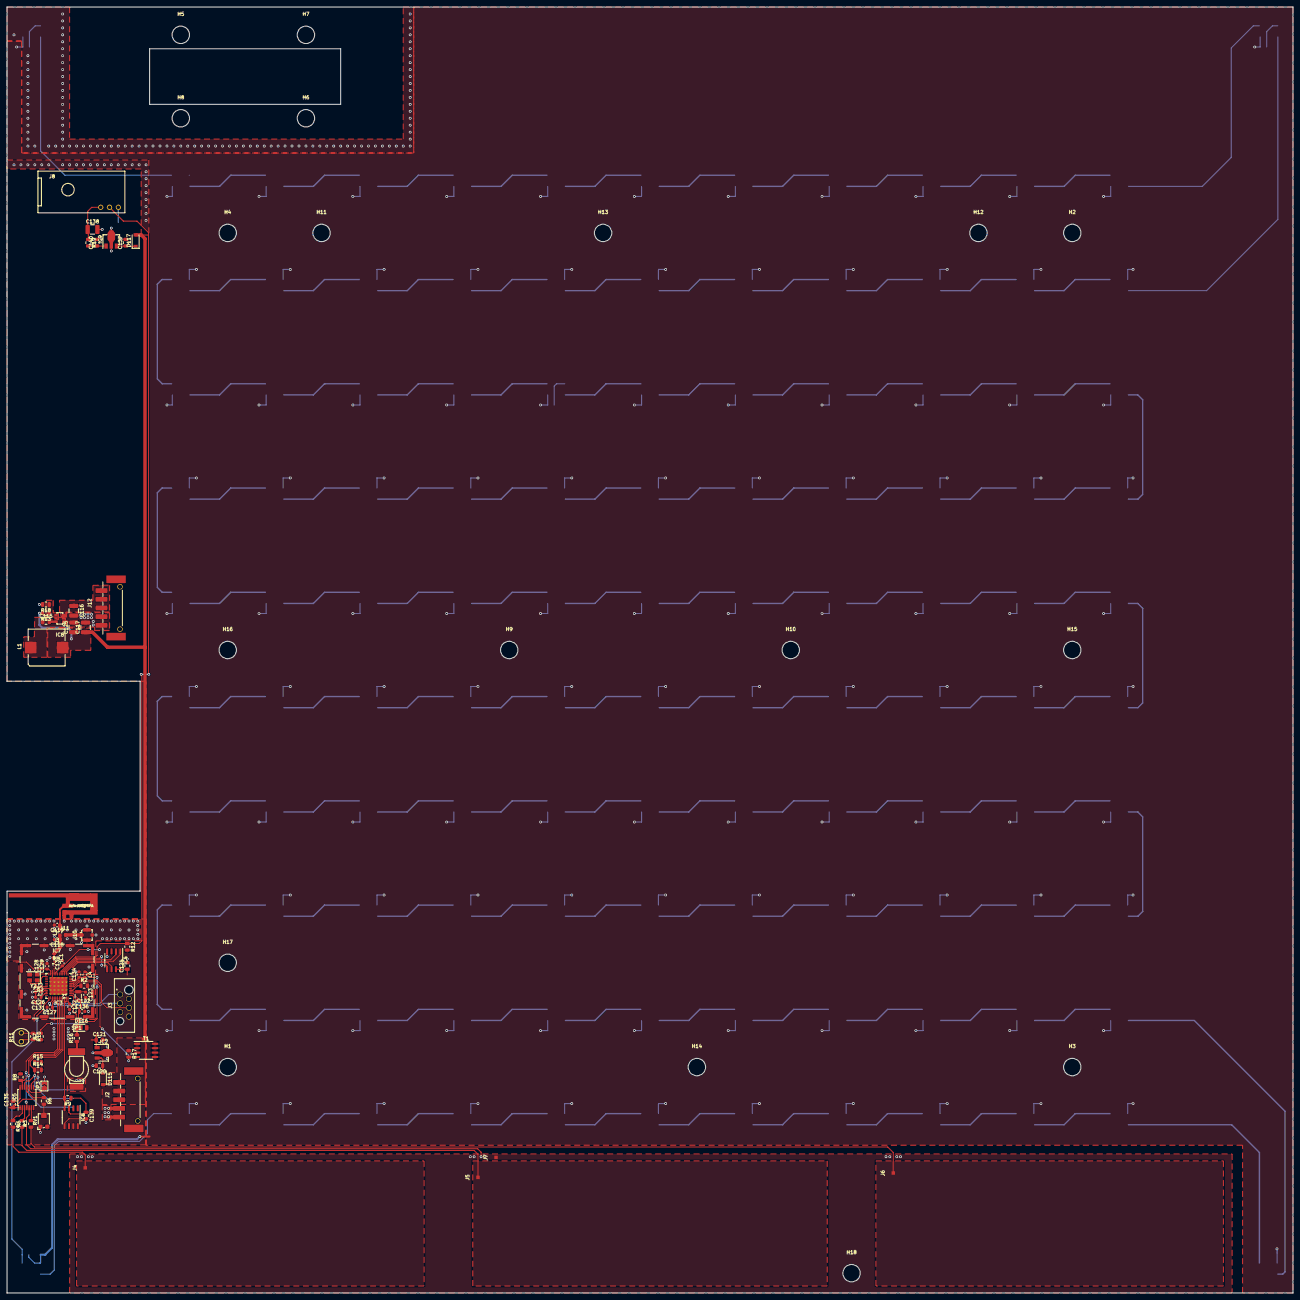
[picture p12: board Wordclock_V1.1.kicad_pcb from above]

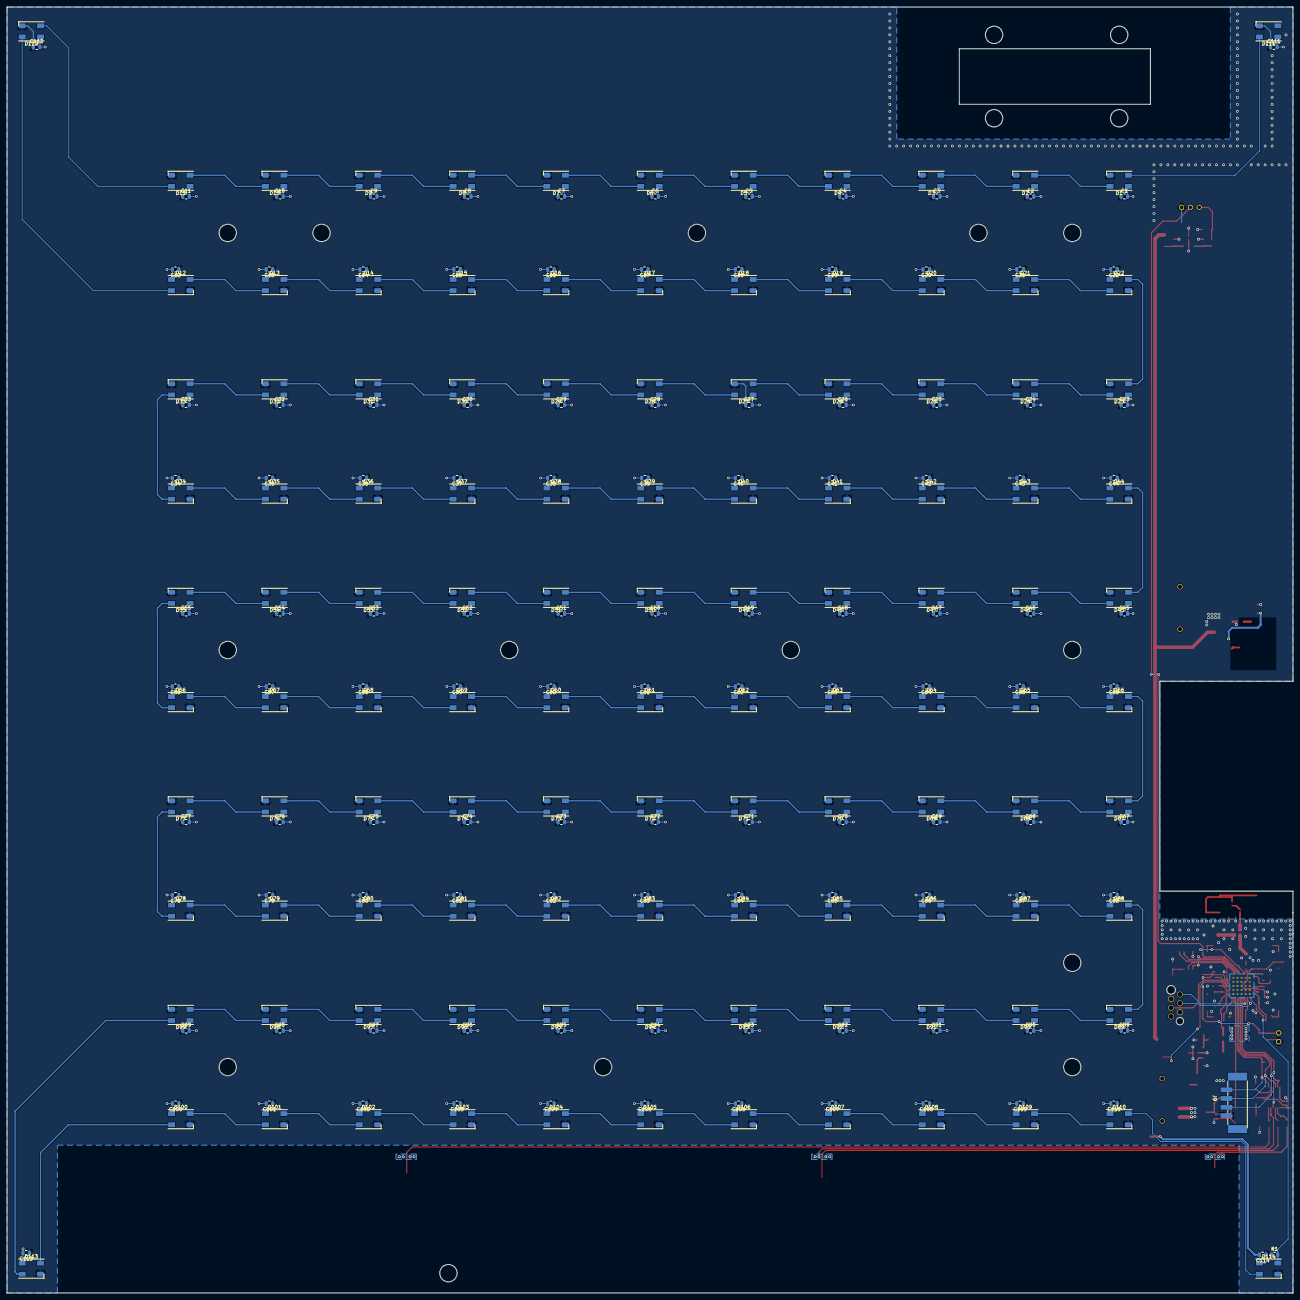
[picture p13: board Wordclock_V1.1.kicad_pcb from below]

Board: 2 copper layers, 370.0 x 370.0 mm, 326 parts (230 on the bottom side), 166 nets.

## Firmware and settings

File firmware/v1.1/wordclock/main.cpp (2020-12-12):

////////////////////////////////////////////////////////////////////////////////
// Wordclock V1.1
// 
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
// You should have received a copy of the GNU General Public License
// along with this program.  If not, see <http://www.gnu.org/licenses/>.
////////////////////////////////////////////////////////////////////////////////
#include "wordclock/wordclock.hpp"

static Wordclock oWordclock;

extern "C" void HardFault_Handler(void){
	oWordclock.oSettings.incErrorCount();
	oWordclock.oSettings.writeChanges();

	/*struct ErrorCode{
		uint32_t u32Key;
		uint32_t u32UFSR;
	} oErrorCode;

	oErrorCode.u32Key = 0x1234ABCD;
	oErrorCode.u32UFSR = ;

	oWordclock.oEEPROM.Write(M95M01::ut32MemSize - sizeof(uint32_t) - sizeof(ErrorCode), (uint8_t *)&oErrorCode, sizeof(ErrorCode));*/

	while (1){
	}
}

extern "C" void TIM2_IRQHandler() {
	TIM2->SR &= ~TIM_SR_UIF;

	Timer::incOverflow();
}

extern "C" int main() {
	while (true) {
		oWordclock.loop();
	}

	return 0;
}

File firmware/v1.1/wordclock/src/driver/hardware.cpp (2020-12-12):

////////////////////////////////////////////////////////////////////////////////
// Wordclock V1.1
// 
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
// You should have received a copy of the GNU General Public License
// along with this program.  If not, see <http://www.gnu.org/licenses/>.
////////////////////////////////////////////////////////////////////////////////
#include "driver/hardware.hpp"

Hardware::Hardware() {
	/*##### RCC #####*/
	RCC->HSECR = 0xCAFECAFE;
	RCC->HSECR = ((0x18) << 8) | 0x30;
	FLASH->ACR = 1;
	RCC->CR |= RCC_CR_HSEON;
	while (!(RCC->CR & RCC_CR_HSERDY));
	RCC->CFGR |= 0b10;
	while ((RCC->CFGR & (0b1000)) != 0b1000);
	RCC->CR &= ~(RCC_CR_HSION);
	//RCC->CFGR |= (0b1000 << 24);
	//RCC->CFGR |= (0b100 << 28); // div 16

	PWR->CR1 |= PWR_CR1_DBP;
	PWR->CR1 |= 0b01ul << 9;
	if (!(RCC->BDCR & RCC_BDCR_LSERDY)) {
		RCC->BDCR |= RCC_BDCR_LSEON;
		while (!(RCC->BDCR & RCC_BDCR_LSERDY));
	}
	RCC->BDCR |= 0b01ul << 8;
	RCC->CCIPR |= 0x03ul << 28;
	PWR->CR4 |= PWR_CR4_C2BOOT;

	/*setting clocks*/
	RCC->AHB2ENR |= RCC_AHB2ENR_GPIOAEN;
	RCC->AHB2ENR |= RCC_AHB2ENR_GPIOBEN;
	RCC->AHB2ENR |= RCC_AHB2ENR_GPIOEEN;
	RCC->BDCR |= RCC_BDCR_RTCEN;
	RCC->APB2ENR |= RCC_APB2ENR_SPI1EN;
	RCC->APB2ENR |= RCC_APB2ENR_USART1EN;
	RCC->APB1ENR1 |= RCC_APB1ENR1_TIM2EN;
	RCC->APB2ENR |= RCC_APB2ENR_TIM1EN;
	RCC->AHB1ENR |= RCC_AHB1ENR_DMA1EN;
	RCC->AHB1ENR |= RCC_AHB1ENR_DMAMUX1EN;
	RCC->AHB2ENR |= RCC_AHB2ENR_ADCEN;

	/* GPIOs */
	STM32::configPinAnalog(GPIOA, 0);    //LDR
	STM32::configPinAF(GPIOA, 1, 5);    //SPI CLK
	STM32::configPinOutput(GPIOA, 2);    //..
	STM32::configPinOutput(GPIOA, 3);    //..
	STM32::configPinOutput(GPIOA, 4);    //..
	STM32::configPinOutput(GPIOA, 5);    //CS EEprom
	STM32::configPinAF(GPIOA, 6, 5);    //SPI MISO
	STM32::configPinAF(GPIOA, 7, 5);    //SPI MOSI
	STM32::configPinInput(GPIOA, 8);    //DCF77
	STM32::configPinOutput(GPIOA, 9);    //..
	STM32::configPinOutput(GPIOA, 10);    //..
	STM32::configPin(GPIOA, 11, STM32::Flags::ALTERNATE, STM32::Flags::OPENDRAIN, STM32::Flags::NOPULL, 1);    //SK6812 Timer
	STM32::configPinOutput(GPIOA, 12);    //..
	//STM32::configPin(GPIOA, 13, STM32::Flags::OUTPUT, STM32::Flags::PUSHPULL, STM32::Flags::NOPULL, 0);
	//STM32::configPin(GPIOA, 14, STM32::Flags::OUTPUT, STM32::Flags::PUSHPULL, STM32::Flags::NOPULL, 0);
	STM32::configPinOutput(GPIOA, 15);    //..
	STM32::configPinOutput(GPIOB, 0);    //..
	STM32::configPinOutput(GPIOB, 1);    //..
	STM32::configPinOutput(GPIOB, 2);    //..
	STM32::configPinInput(GPIOB, 3);    //MTO0
	STM32::configPinInput(GPIOB, 4);    //MTO1
	STM32::configPinInput(GPIOB, 5);    //MTO3
	STM32::configPin(GPIOB, 6, STM32::Flags::ALTERNATE, STM32::Flags::OPENDRAIN, STM32::Flags::NOPULL, 7);    //OneWIre
	STM32::configPin(GPIOB, 7, STM32::Flags::ALTERNATE, STM32::Flags::OPENDRAIN, STM32::Flags::NOPULL, 7);    //OneWIre
	STM32::configPinOutput(GPIOB, 8);    //..
	STM32::configPin(GPIOB, 9, STM32::Flags::OUTPUT, STM32::Flags::OPENDRAIN, STM32::Flags::NOPULL, 0);    //Power LED
	STM32::configPinOutput(GPIOE, 4);    //..

	/*RTC*/
	RTC->WPR = 0xCA;
	RTC->WPR = 0x53;
	//RTC->CR |= RTC_CR_COE;
	//RTC->OR |= (1 << 1);
	RTC->CALR = (uint32_t) (512 - 19) | RTC_CALR_CALP;

	/* Timer für Interrupt */
	TIM2->ARR = 0xffffffff;
	TIM2->CNT = 0xffffffff;
	TIM2->DIER = TIM_DIER_UIE;
	TIM2->PSC = (CLK_TIMER / 1000000ul) - 1;
	TIM2->CR1 = TIM_CR1_CEN;
	STM32::setInterrupt(TIM2_IRQn, 1);
	Timer::setReference((uint32_t*) &TIM2->CNT);

	/* Timer für SK6812 */
	DMAMUX1_Channel0->CCR = 25 << DMAMUX_CxCR_DMAREQ_ID_Pos;
	DMA1_Channel1->CCR = DMA_CCR_MINC | (0b00 << 10) | (0b01 << 8) | DMA_CCR_DIR;
	TIM1->CR1 = 0;
	TIM1->DIER = TIM_DIER_UDE;
	TIM1->CCMR2 = (0b110UL << 12) | TIM_CCMR2_OC4PE;
	TIM1->CCER = TIM_CCER_CC4E;
	TIM1->ARR = (CLK_TIMER / CLK_SK6812) - 1;
	TIM1->CCR4 = 0;
	TIM1->BDTR = TIM_BDTR_MOE;
	TIM1->CR1 = TIM_CR1_CEN;

	/* LDR */
	ADC1->CR &= ~ADC_CR_DEEPPWD;
	ADC1->CR |= ADC_CR_ADVREGEN;
	Timer t(10);
	while (!t.Ready());
	ADC1->CR |= ADC_CR_ADCAL;
	while (ADC1->CR & ADC_CR_ADCAL);
	ADC1->SMPR1 = (0b111ul << 15);
	ADC1->SQR1 = 5 << 6;
	ADC1->CR |= ADC_CR_ADEN;
	while (!(ADC1->ISR & ADC_ISR_ADRDY));
	ADC1->CFGR &= ~ADC_CFGR_JQDIS;
	ADC1->CR |= ADC_CR_ADSTART;

#ifndef DEBUG
	/* Watchdog */
	RCC->APB1ENR1 |= RCC_APB1ENR1_WWDGEN;
	WWDG->CFR = 0x7f;
	WWDG->CFR |= 0b111ul << 11;
	WWDG->CR = WWDG_CR_WDGA | 0x7e;
#endif
}

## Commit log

2020-12-23 stencil layouts
    [De_laser.dxf, Nl_laser.dxf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]
2020-12-26 en laser stencil
2021-01-14 timezone dcf77
    [Taster-B_Cu.gbr, Taster-B_Mask.gbr, Taster-B_SilkS.gbr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]

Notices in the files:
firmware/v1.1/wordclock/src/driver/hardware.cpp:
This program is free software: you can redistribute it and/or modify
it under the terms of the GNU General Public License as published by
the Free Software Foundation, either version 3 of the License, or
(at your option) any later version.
